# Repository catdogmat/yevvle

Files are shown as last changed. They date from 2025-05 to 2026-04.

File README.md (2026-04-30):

# Yevvle

E-Ink ESP32 powered Watch that might at some point be able to run pebble apps.

## What is it?

The main porpose of LightInk project is to have a functional and basic E-Ink watch that can be powered via Solar cell entirely. The power consumption is around 2uA just updating time, therefore a 200mAh battery like "Watchy" has can last around 400 days! (or powered by a small solar cell)

The project is based around the "Watchy" idea, but requires specific HW to reach these low power levels. Basically differs in:
* Has a better TPS63900 power source of 2.6/2.9V
  * More efficient (DC-DC 75nA quiscent, 1A, 1.8-5V regulation, which 2 configurable voltages)
  * This is enough to power ESP32/RTC/Eink and WiFi under all conditions
* Does not have accelerometer (too much power!, even disabled, uses 1uA)
* Does not have solar cell regulation, is connected directly to batery
* Piezo speaker support
* LED light to see display in dark
* Capacitive touch instead of buttons
* Support for LORA/GPS, but yes, they use too much power! (only turn on to send a signal)

## What is done already ?

The project goals are:
- [X] Ultra low consumption <0.5 mAh/day!
  - [X] Custom Display Driver, reduce booster times/ LUT, etc..
  - [X] Implement a uSPI and display update from wake sleep stub (<1ms! ESP32 on time)
- [X] Basic UI functionality and Widgets
- [X] Features
  - [X] LED light
  - [X] Vibration
  - [X] Speaker
  - [X] GPS
  - [X] Lora receive, BPSK send signals
- [X] Time accurate
  - [X] Manual calibrate drift and adjust it
  - [X] 1ppm Target (now 10ppm)
  - [X] NTP sync - Wifi - AutoZone
- [X] Battery Power support
  - [ ] Track battery & estimate in ULP
  - [X] Auto power save
  - [X] Night time, saving ours
- [X] Touch Settings
  - [X] Capacitive Touch functionality
  - [X] Touch configuration - Sensitivity
- [ ] Watchface configuration
  - [ ] Refactor watchface to be modular with uSPI update
  - [X] Moon Indicator
  - [X] SunSet Sunrise
  - [ ] Tides
  - [ ] Pictures, etc
- [ ] Configurable Alarms
- [ ] BT - Companion App
- [ ] Support other boards
  - [ ] Watchy v1.0 -> [Watchy 1.0 Branch](https://github.com/DarkZeros/LightInk/tree/watchy_1.0)

## Repo structure

lightink/
├── firmware/
│   ├── main/         # The LightInk firmware code
│   ├── components/   # Other components & subprojects used in the builds
│   └── esp-idf/      # The ESP-IDF version used to build (it has changes compared to upstream)
│   ...               # Other misc files like partitions / sdkconfig / ...
│
├── hardware/
│   ├── pcb/          # Schematics, BOM and diagrams
│   └── case/         # STL files for from and back
│
├── docs/
│   ├── images/       # images of the project
│   ...               # Hisotory and important docs
│
├── README.md
└── LICENSE

## More info

- 📖 [History](docs/history.md)
- 🛠️ [Hardware - Case](hardware/case/CASE.md)
- 🛠️ [Hardware - PCB](hardware/pcb/PCB.md)

## How to build the firmware?

It should be quite straightforward:
Just clone everything (`git submodule update --init --recursive`)
`cd firmware && ./setup.sh && idf.py build flash monitor`

## Helping the project

Just push to a non protected branch and ask for PR.
Any contribution is welcomed.

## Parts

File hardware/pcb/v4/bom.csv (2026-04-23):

ID | Name | Designator | Footprint | Quantity | Manufacturer Part | Manufacturer | Supplier | Supplier Part | Price
1 | BUZZ | BUZZ | VIBRATING-MOTOR-SMD_WELDING | 1
2 | ANTENNA 868MHZ | 868MHZ | ANTENNA 868MHZ | 1
3 | 100nF | C16,C15 | C0402 | 2 | CC0402KRX7R7BB104 | YAGEO(国巨) | LCSC | C60474 | 0.001
4 | 10kΩ | R13,R3,R12 | R0603 | 3 | RMC060310KFN | Tyohm(幸亚电阻) | LCSC | C269701 | 0.004
5 | SWRA117D | AE1 | SWRA117D | 1
6 | 3Ω | R8 | R0603 | 1 | 0603WAF300KT5E | UNI-ROYAL(厚声) | LCSC | C23157 | 0.002
7 | UMH3N | Q4 | SC-70-6_L2.2-W1.3-P0.65-LS2.1-BR | 1 | UMH3N | CJ(江苏长电/长晶) | LCSC | C62892 | 0.049
8 | Vibration_Motor | M1 | VIBRATING-MOTOR-SMD_WELDING | 1
9 | CJ2301 S1 | Q2,Q6 | SOT-23-3_L3.0-W1.7-P0.95-LS2.9-BR | 2 | CJ2301 S1 | CJ(江苏长电/长晶) | LCSC | C8547 | 0.025
10 | 22uF | C1 | C0603 | 1 | 0603X226M6R3CT | Walsin(华新科) | LCSC | C93926 | 0.017
11 | 10uF | C2 | C0603 | 1 | GRM188R60J106ME47D | muRata(村田) | LCSC | C77041 | 0.014
12 | 4.7uF | C6 | C0603 | 1 | CL10A475KP8NNNC | SAMSUNG(三星) | LCSC | C1705 | 0.006
13 | 1uF | C7,C8,C9,C10,C11,C12 | C0603 | 6 | 0603F105M500NT | FH(风华) | LCSC | C108343 | 0.008
14 | 4.7uF | C13,C14 | C0603 | 2 | GRM188R6YA475KE15D | muRata(村田) | LCSC | C162274 | 0.037
15 | 1kΩ | R10,R11 | R0402 | 2 | 0402WGF1001TCE | UNI-ROYAL(厚声) | LCSC | C11702 | 0.001
16 | MICROQTJ | USB1 | MICRO-USB-SMD_MICROQTJ | 1 | MicroQTJ | SHOU HAN | LCSC | C404968 | 0.035
17 | 511Ω | R2 | R0603 | 1 | RC0603FR-07511RL | YAGEO(国巨) | LCSC | C137703 | 0.001
18 | 16.2kΩ | R1 | R0603 | 1 | RMC 0603 16K2 F N | Tyohm(幸亚电阻) | LCSC | C269411 | 0.003
19 | 1kΩ | R4 | R0603 | 1 | RMC06031K1%N | Tyohm(幸亚电阻) | LCSC | C269704 | 0.003
20 | 10MΩ | R5,R6 | R0603 | 2 | RC0603FR-0710ML | YAGEO(国巨) | LCSC | C114606 | 0.002
21 | 20kΩ | R7 | R0603 | 1 | RT0603BRD0720KL | YAGEO(国巨) | LCSC | C723637 | 0.024
22 | 100kΩ | R9 | R0603 | 1 | RC0603FR-07100KL | YAGEO(国巨) | LCSC | C14675 | 0.001
23 | CP2104-F03-GM | U4 | QFN-24_L4.0-W4.0-P0.50-BL-EP2.7 | 1 | CP2104-F03-GMR | SILICON LABS(芯科) | LCSC | C47742 | 2.202
24 | NCD0603O3 | U6 | LED0603-RD | 1 | NCD0603O3 | 国星光电 | LCSC | C7429913 | 0.007
25 | PCF8563TS/5,118 | U8 | TSSOP-8_L3.0-W3.0-P0.65-LS4.9-BL | 1 | PCF8563TS/5,118 | NXP(恩智浦) | LCSC | C27397 | 0.88
26 | TP4054_C668215 | U5 | TSOT-23-5_L2.9-W1.6-P0.95-LS2.8-BR | 1 | TP4054 | UMW(广东友台半导体) | LCSC | C668215 | 0.041
27 | Light | LIGHT | VIBRATING-MOTOR-SMD_WELDING | 1
28 | 32.768kHz | X1 | CRYSTAL-SMD_L3.2-W1.5 | 1 | Q13FC13500005 | EPSON(爱普生) | LCSC | C841881 | 0.281
29 | 2.2uH | L1 | L1008 | 1 | DFE252010F-2R2M=P2 | muRata(村田) | LCSC | C488330 | 0.176
30 | TPS63900DSKR | U2 | WSON-10_L2.5-W2.5-W0.50-TL-EP | 1 | TPS63900DSKR | TI(德州仪器) | LCSC | C1518762 | 1.307
31 | 10uH | U7 | L0806 | 1 | DFE201610E-100M=P2 | muRata(村田) | LCSC | C426327 | 0.158
32 | AO3400A | Q1 | SOT-23_L2.9-W1.3-P1.90-LS2.4-BR | 1 | AO3400A | BORN(伯恩半导体) | LCSC | C344010 | 0.06
33 | MBR0530 | D3,D2,D1,D4 | SOD-123_L2.7-W1.6-LS3.7-RD-1 | 4 | MBR0530 | SHIKUES(时科) | LCSC | C475718 | 0.019
34 | S8050 | Q3 | SOT-23-3_L2.9-W1.3-P1.90-LS2.4-BR | 1 | S8050 | ElecSuper(静芯微） | LCSC | C5249674 | 0.01
35 | 1N4001WS | D5 | SOD-323_L1.6-W1.3-LS2.7-RD | 1 | 1N4001WS | YFW(佑风微) | LCSC | C2898400 | 0.02
36 | AFC07-S24ECA-00 | FPC1 | FPC-SMD_AFC07-S24ECA-00 | 1 | AFC07-S24ECA-00 | JS(钜硕电子) | LCSC | C262643 | 0.099
37 | - | U3 | LGA-48_L7.0-W7.0-P0.50-BL-EP5.4 | 1 | ESP32-PICO-D4 | ESPRESSIF(乐鑫) | LCSC | C193707 | 4.182

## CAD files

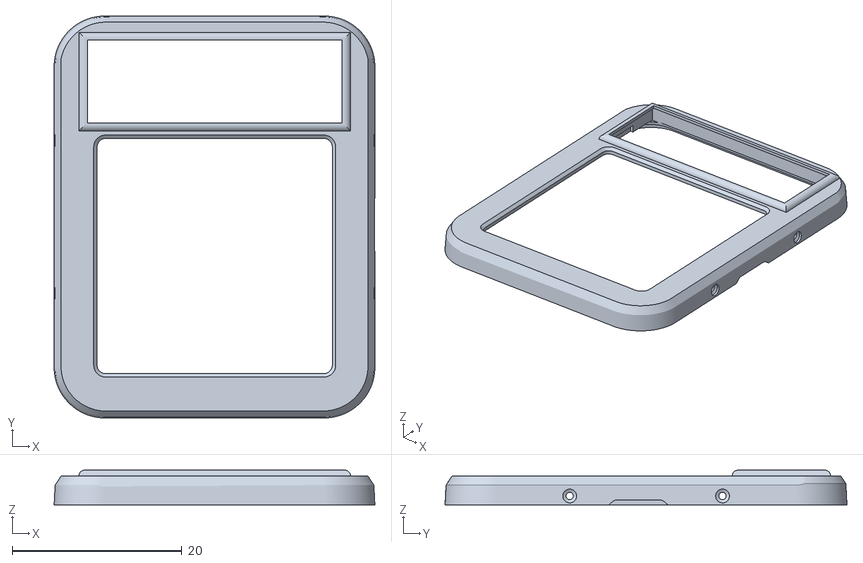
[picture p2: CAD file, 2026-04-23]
hardware/case/v14/Front Case.stl
37.8 x 47.4 x 4.10

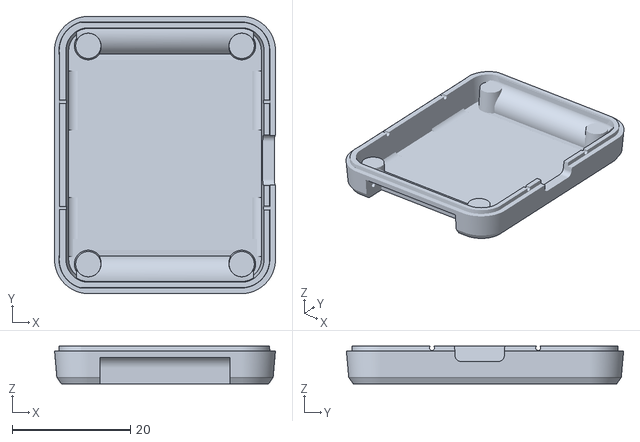
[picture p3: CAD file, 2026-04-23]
hardware/case/v14/Rear Case.stl
37.5 x 47.0 x 6.40

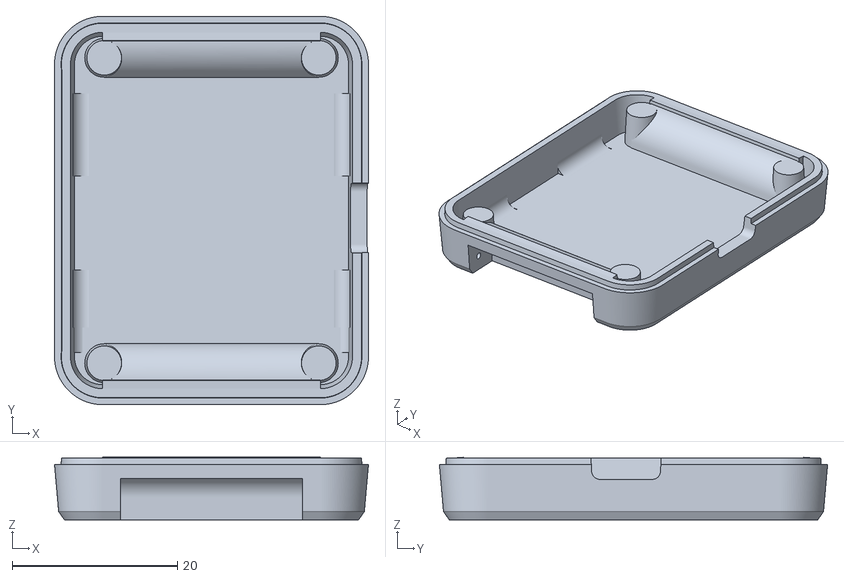
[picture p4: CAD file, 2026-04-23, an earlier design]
hardware/case/v8/Rear Case.stl
38.0 x 47.0 x 7.59

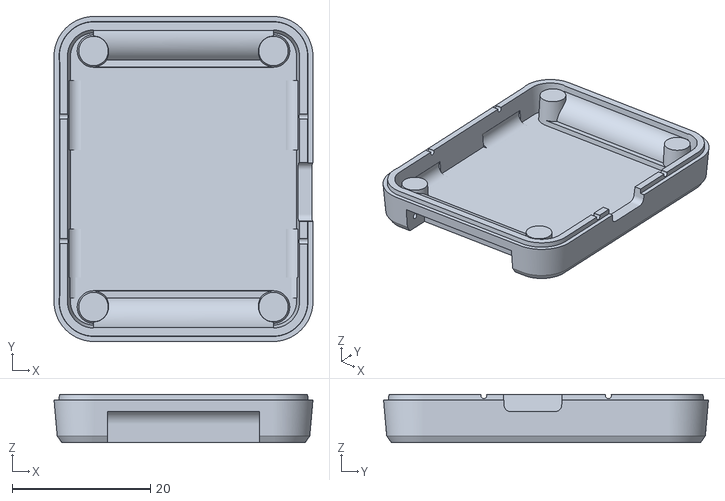
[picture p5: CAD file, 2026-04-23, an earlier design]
hardware/case/v13/Rear Case.stl
37.4 x 47.0 x 7.00

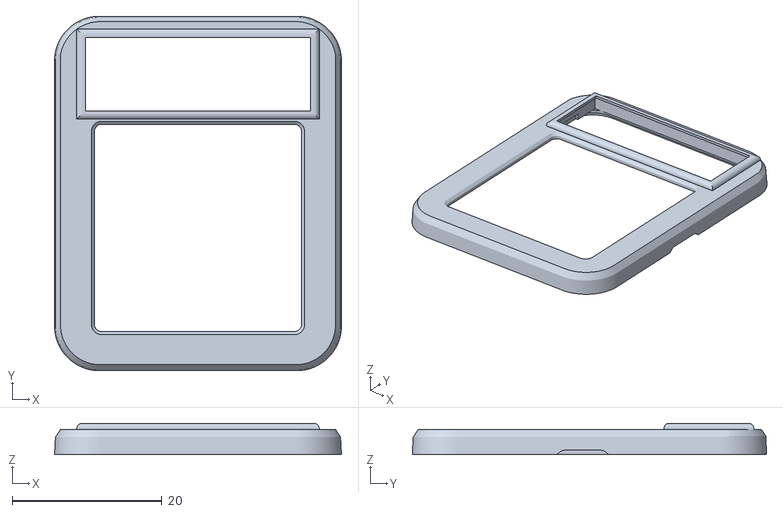
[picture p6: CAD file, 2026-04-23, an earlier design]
hardware/case/v8/Front Case.stl
38.3 x 47.4 x 4.20

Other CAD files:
hardware/case/v13/Front Case.stl

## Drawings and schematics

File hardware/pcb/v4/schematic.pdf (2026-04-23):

ESP32 Pico D4 | Power - USB power | Display

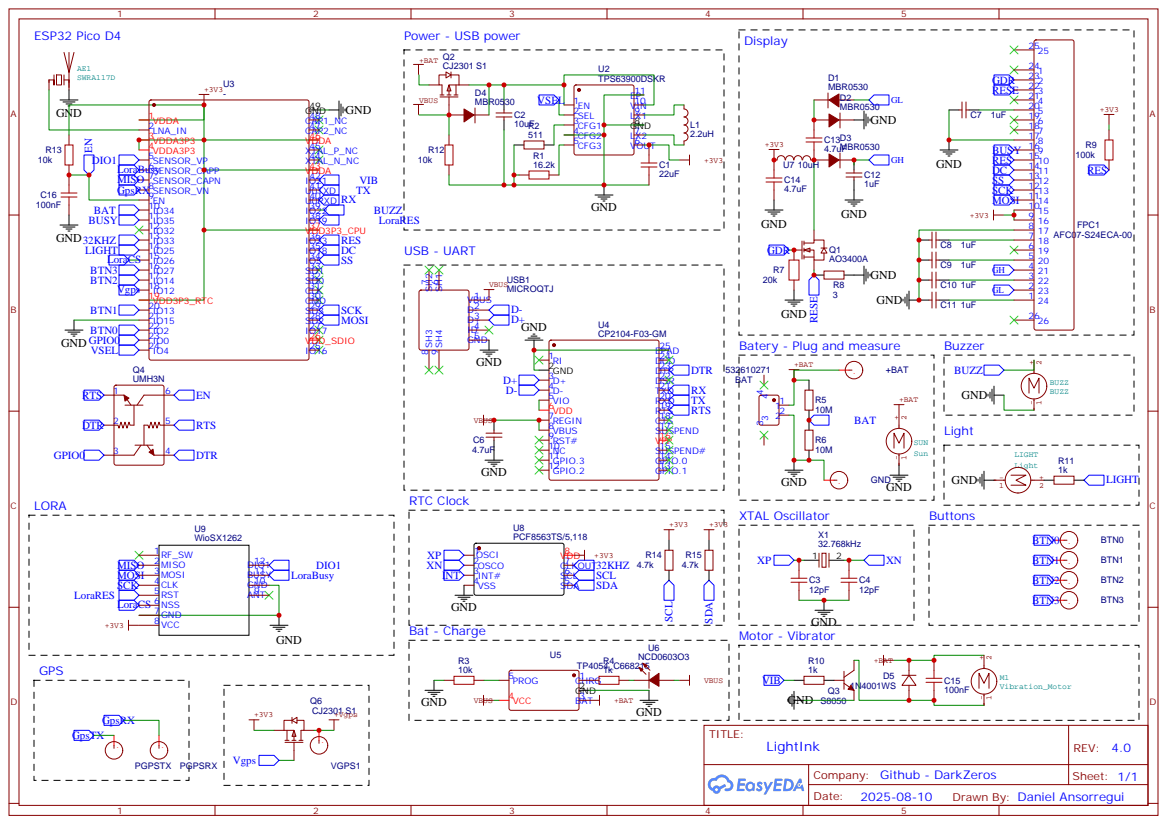
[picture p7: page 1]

Batery - Plug and measure

Drawn By: Daniel Ansorregui

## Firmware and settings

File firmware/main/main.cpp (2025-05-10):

#include "core.h"
#include "esp_pm.h"

Core& getInstance() {
    static Core instance; // Lazily initialized on first call
    return instance;
}

extern "C" {
void app_main(void) {
    // Enable PM for auto sleep while executing
    esp_pm_config_t pm_config = {
        .max_freq_mhz = CONFIG_ESP_DEFAULT_CPU_FREQ_MHZ,
        .min_freq_mhz = CONFIG_ESP_DEFAULT_CPU_FREQ_MHZ,
        .light_sleep_enable = true
    };
    esp_pm_configure(&pm_config);

    getInstance();
}
}

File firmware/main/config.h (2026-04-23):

#ifndef CONFIG_H
#define CONFIG_H

// Versioning
#define WATCHY_LIB_VER "1.4.7"

//pins
#if !defined(ARDUINO_WATCHY_V10) && !defined(ARDUINO_WATCHY_V15) && !defined(ARDUINO_WATCHY_V20)

#pragma message "Please install the latest ESP32 Arduino Core (2.0.5+) and choose Watchy as the target board"
#pragma message "Hardware revision is not defined at the project level, please define in config.h. Defaulting to ARDUINO_WATCHY_V20"

//Change to your board version
#define ARDUINO_WATCHY_V20

#define MENU_BTN_PIN 26
#define BACK_BTN_PIN 25
#define DOWN_BTN_PIN 4
#define DISPLAY_CS 5
#define DISPLAY_RES 9
#define DISPLAY_DC 10
#define DISPLAY_BUSY 19
#define ACC_INT_1_PIN 14
#define ACC_INT_2_PIN 12
#define VIB_MOTOR_PIN 13
#define RTC_INT_PIN 27

#if defined (ARDUINO_WATCHY_V10)
    #define UP_BTN_PIN 32
    #define BATT_ADC_PIN 33
    #define UP_BTN_MASK (uint64_t(1)<<GPIO_NUM_32)
    #define RTC_TYPE 1 //DS3231
#elif defined (ARDUINO_WATCHY_V15)
    #define UP_BTN_PIN 32
    #define BATT_ADC_PIN 35
    #define UP_BTN_MASK (uint64_t(1)<<GPIO_NUM_32)
    #define RTC_TYPE 2 //PCF8563
#elif defined (ARDUINO_WATCHY_V20)
    #define UP_BTN_PIN 35
    #define BATT_ADC_PIN 34
    #define UP_BTN_MASK (uint64_t(1)<<GPIO_NUM_35)
    #define RTC_TYPE 2 //PCF8563
#endif

#define MENU_BTN_MASK (uint64_t(1)<<GPIO_NUM_26)
#define BACK_BTN_MASK (uint64_t(1)<<GPIO_NUM_25)
#define DOWN_BTN_MASK (uint64_t(1)<<GPIO_NUM_4)
#define ACC_INT_MASK  (uint64_t(1)<<GPIO_NUM_14)
#define BTN_PIN_MASK  MENU_BTN_MASK|BACK_BTN_MASK|UP_BTN_MASK|DOWN_BTN_MASK

#endif

//display
#define DISPLAY_WIDTH 200
#define DISPLAY_HEIGHT 200
// wifi
#define WIFI_AP_TIMEOUT 60
#define WIFI_AP_SSID    "Watchy AP"
// menu
#define WATCHFACE_STATE -1
#define MAIN_MENU_STATE 0
#define APP_STATE       1
#define FW_UPDATE_STATE 2
#define MENU_HEIGHT     25
#define MENU_LENGTH     7
// set time
#define SET_HOUR   0
#define SET_MINUTE 1
#define SET_YEAR   2
#define SET_MONTH  3
#define SET_DAY    4
#define HOUR_12_24 24
// BLE OTA
#define BLE_DEVICE_NAME        "Watchy BLE OTA"
#define WATCHFACE_NAME         "Watchy 7 Segment"
#define SOFTWARE_VERSION_MAJOR 1
#define SOFTWARE_VERSION_MINOR 0
#define SOFTWARE_VERSION_PATCH 0
#define HARDWARE_VERSION_MAJOR 1
#define HARDWARE_VERSION_MINOR 0
#endif

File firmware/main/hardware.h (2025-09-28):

#pragma once

#include <cstdint>
#include <array>
#include <sdkconfig.h>

#if CONFIG_IDF_TARGET_ESP32S3
#define HW_VERSION 10 // First WIP board
#else
#define HW_VERSION 4 // Last board fully working
#endif

enum class HW_chips {ESP_32, ESP_32_S3};

// Original ESP32-PICO-D4 board based off from Watchy
// there were 2 previous revisions with wrong wiring/touch/chip
// that I am not even going to ever cover with code
struct HW_1 {
    constexpr static uint8_t kVersion = 1;
    constexpr static HW_chips kChipType = HW_chips::ESP_32;
    constexpr static bool kHasLowVoltage = true;
    constexpr static bool kVoltageSelectInverted = false;
    constexpr static bool kHasLora = false;
    constexpr static bool kHasGps = false;
    constexpr static bool kHasDisplayBusyWake = false;

    struct Touch {
        enum PadNames {BotR /*Down*/, TopR /*Up*/, TopL /*Menu*/, BotL /*Back*/};
        constexpr static std::array<uint8_t, 4> Pad = {{6,0,2,5}};
    };

    struct Spi {
        constexpr static uint8_t Sck = 18;
        constexpr static uint8_t Miso = -1; 
        constexpr static uint8_t Mosi = 23;
    };

    struct Display {
        constexpr static uint8_t Cs = 5;
        constexpr static uint8_t Res = 9;
        constexpr static uint8_t Dc = 10; // 8 bit transfer mode
        constexpr static uint8_t Busy = 19; // 35 better, never manufactured
    };
    
    struct Gps {
        // constexpr static uint8_t Tx = -1;
        constexpr static uint8_t Rx = -1;
        constexpr static uint8_t Vcc = -1; // RTC reqired
        constexpr static auto BaudRate = 115200;
    };
    struct Lora {
        constexpr static uint8_t Cs = -1; // RTC reqired
        constexpr static uint8_t Res = -1;
        constexpr static uint8_t Busy = -1; // Input only pin
        constexpr static uint8_t Dio1 = -1; // IRQ // Input only pin
    };

    constexpr static uint8_t kAdcPin = 34;
    constexpr static uint8_t kLightPin = 25;
    constexpr static uint8_t kSpeakerPin = 26;
    constexpr static uint8_t kVibratorPin = 27;
    constexpr static uint8_t kVoltageSelectPin = 13;

    // Unused but available in V1 and V2
    // constexpr static uint8_t kRtcIntPin = 32;
    // constexpr static uint8_t kSdaPin = ??;
    // constexpr static uint8_t kSclPin = ??;
};

// Minor changes done to the board
struct HW_2 : public HW_1 {
    constexpr static uint8_t kVersion = 2;
    constexpr static bool kVoltageSelectInverted = true;
};

// Added Lora/GPS to PICOD4, reshuffle pins
// Use as much as possible INPUT ONLY pins 34-39
// NOTE: I never build a final version out of this HW
//       since it didn´t fit on a small case
struct HW_3 : public HW_2 {
    constexpr static uint8_t kVersion = 3;
    constexpr static bool kHasLora = true;
    constexpr static bool kHasGps = true;
    constexpr static bool kHasDisplayBusyWake = true;

    struct Spi {
        constexpr static uint8_t Sck = 10;
        constexpr static uint8_t Miso = 38; 
        constexpr static uint8_t Mosi = 9;
    };

    struct Display {
        constexpr static uint8_t Cs = 5;
        constexpr static uint8_t Res = 23;
        constexpr static uint8_t Dc = 18; // Could be 9 bit transfer and avoid this pin
        constexpr static uint8_t Busy = 35; // RTC required // Input only pin
    };

    struct Lora {
        constexpr static uint8_t Cs = 26; // RTC reqired
        constexpr static uint8_t Res = 19;
        constexpr static uint8_t Busy = 37; // Input only pin
        constexpr static uint8_t Dio1 = 36; // IRQ // Input only pin
    };

    struct Gps {
        constexpr static uint8_t Rx = 39; // Input only pin
        constexpr static uint8_t Vcc = 27; // RTC required
        constexpr static auto BaudRate = 115200;
    };

    constexpr static uint8_t kAdcPin = 34;
    constexpr static uint8_t kLightPin = 25; // RTC required
    constexpr static uint8_t kSpeakerPin = 22;
    constexpr static uint8_t kVibratorPin = 21;
    constexpr static uint8_t kVoltageSelectPin = 13; // RTC required
};

// Minor changes to accomodate HW_3 issues into a smaller board
struct HW_4 : public HW_3 {
    constexpr static uint8_t kVersion = 4;
    // constexpr static bool kHasLora = false;
    // constexpr static bool kHasGps = false;
    // constexpr static bool kHasDisplayBusyWake = false;
    // constexpr static bool kHasLowVoltage = false;

    struct Touch {
        enum PadNames {BotR /*Down*/, TopR /*Up*/, TopL /*Menu*/, BotL /*Back*/};
        constexpr static std::array<uint8_t, 4> Pad = {{7, 2, 4, 6}};
    };

    struct Gps {
        constexpr static uint8_t Rx = 39; // Input only pin
        constexpr static uint8_t Vcc = 12; // RTC required
        constexpr static auto BaudRate = 115200;
    };

    constexpr static uint8_t kVoltageSelectPin = 4; // RTC required
};
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

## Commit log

2024-12-12 Power Save modes
2024-12-31 Fix DeepSleep Display modes
    * It needs a different BusyWait per LUT
    * It could go negative otherwise and cause
    big issues, like display not updating at all
    [deep_sleep.cpp, display.cpp, display.h]
2024-12-31 UI Bool/Loop rework simplification
    * Remove the bitfields, where saving some
    bits, but insignificant (7Bytes?)
    * Making the rest of code simpler
    [core.cpp, display.h]
2025-05-10 Backup current SDK config
2025-05-10 Support both ESP32 & S3
2025-05-10 Full working ESP32-S3 HW support
    + Still WIP
    + All the LUT improvements!
    + Update to v5.4!
2025-05-10 Fix UI crahs on navigation
    [core.cpp]
2025-06-06 Lora mega patch
    * Working Lora draft, low power, RTC stored
    * Refactored SPI separated from display
    * Refactored initial setup/configuration
    * Upgraded UI in menus slightly
    * Completely reworked Touch for V3 more modular
    - Modified upstream version to fix touch issue
    [core.cpp, deep_sleep.cpp, display.cpp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]
2025-06-07 Add remove ISR handler to avoid bootloop
    * If the ISR is kept, it will trigger at boot
    (even if the Interrupt is manually disabled)
    [display.cpp]
2025-07-02 Using RTC_SLOW instead of IRAM
    * This places the code in memory available
    for fast/slow RTC avoiding issues if they
    are called from any CPUs
    * Moves 600B RTC_FAST -> RTC_SLOW
    64.7% -> 72.3% RTC_SLOW
    33.8% -> 26.5% RTC_FAST
    [light.cpp, power.cpp]
2025-07-02 HWV3
    * Proper pins everywhere for HW_V3!
    * Fixed PD domain, added EXT0 out of spec working
    * Fix issue in Display not disabling the GPIO wakeuo
    * Fully redone the Wakeup EXT0 deep sleep to be working and simpler
    * TODO: Still pending to fix RadioLib when chip is not connected
    [core.cpp, deep_sleep.cpp, display.cpp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]
2025-07-02 Fix task not executing in Core
    [core.cpp]
2025-07-03 Power lock unlock flags
2025-07-07 New Power::Lock class
2025-07-13 Fix GPS lock and auto turn off
    * Only wait 200ms maximum
    * Automatic turn off the power after lock
    * Keep Full update during GPS search
    [core.cpp, gps.cpp]
2025-07-13 Fix HW_V3 (HW_V3.2)
    * Moved Vibrator to pin 21 (no rtc)
    * Moved Lora_CS to pin 26 (RTC)
    * Removed pin 32, can´t be used with external CLK
    [hardware.h]
2025-07-15 Fix battery measures in 1.9/2.8V
    [battery.cpp, core.cpp]
2025-07-15 GPS next update and fixes
    [core.cpp, gps.cpp]
2025-07-20 Fastest lora OOK radio configuration
    * Fixes problem in ESP32-D4 OOK
    * Tested Radio works fine, power is ~0uA sleeping
    [core.cpp]
2025-07-20 Minor fixes to Power/DeepSleep Utils and GPS
    [deep_sleep_utils.cpp, gps.cpp]
2025-07-20 Fix GPS and nextTime earlywake
    [core.cpp]
2025-07-20 Refactor Radio & Create secrets
    * Refactor Lora to Radio, since is more than just Lora
    * Move radio signals to secrets.cpp
    * Generate custom Menus for radio signals
    * Fixes to Lora/Radio
    [core.cpp, radio.cpp]
2025-09-28 HW_V4
    * Minor fixups to Lora
    * Fixed the RTC CS Lora hold
    * Remove as many hardcoded defines
    * Fixed watchface on early wakes
    [core.cpp, hardware.h, radio.cpp]
2025-09-28 Fixes to HW v4
    * Allow Gps Resync
    * Fix Touch pins, change default sens to 60
    * Proper fix Lora
    - XTAL is false on Seeed Wio module
    -
    [core.cpp, hardware.h, radio.cpp]
2025-10-12 Add partitions.csv default
    [partitions.csv]
2025-12-22 Start radio in low power and correct freq
    [radio.cpp]
2026-03-01 Touch fixes for phantom touch
    * Fixed by setting the touch after touch events
    This allows enough time for events to settle
    * Enable touch trigger at the end, avoids issues
    * Also cache the touch mode to avoid resetting
    [core.cpp]
2026-03-01 Allow to disable LowVoltage
    * Display has slightly less quality
    using low voltage
2026-03-26 Updated IDF 5.5.1 + Arduino 3.3.5
    - 911kB (Arduino 3.3 + IDF 5.5)
    - 934kB (Arduino 3.3.5 + IDF 5.5)
    - 938kB (Arduino 3.3.5 + IDF 5.5.1)
2026-03-29 Use IDF5.5.3 + Arduino3.3.1 component
    * Easier!
    * Uses a little bit more space, but is ok
2026-04-17 Wifi multiAP and NTP fixes
    * Allow multiAP wifi secrets
    * NTP gets location as well for setting sun without GPS
    [partitions.csv]
2026-04-17 Found out quality in display issue
    * Culprit is Booster time adjustments
    Need to pinpoint power usage and benefits...
    * Maybe create an option, low quality high quality...
    * TODO meadure costs!!
    [core.cpp, display.cpp, display.h]
2026-04-17 More display optimizations
    * Replace /% with >> and &
    [display.cpp]
2026-04-23 Reorganize repository for release
    * Place everything under firmware/
    Making space for other folders
    [partitions.csv]
2026-04-23 Add PCB/Case files
    [Front Case.stl, Rear Case.stl, bom.csv]
